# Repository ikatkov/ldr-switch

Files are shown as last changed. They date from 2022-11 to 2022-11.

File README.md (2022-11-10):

# Tiny LDR switch

Based on $0.60 Attiny13 MCU. 1kB flash, 256B ram.

It turns ON when it's dark (user configurable), stays ON for X hours, turns OFF, and waits till it's dark again. Intended to use with a battery, so it only consumes 5uA. Watch out for input power voltage. Min is 1.8V max is 5.5V. Max load current ~2A. Exceeds this and PCB traces will heat up and unsolder components.
There is simple diode craw-bar reverse voltage protection for MCU.

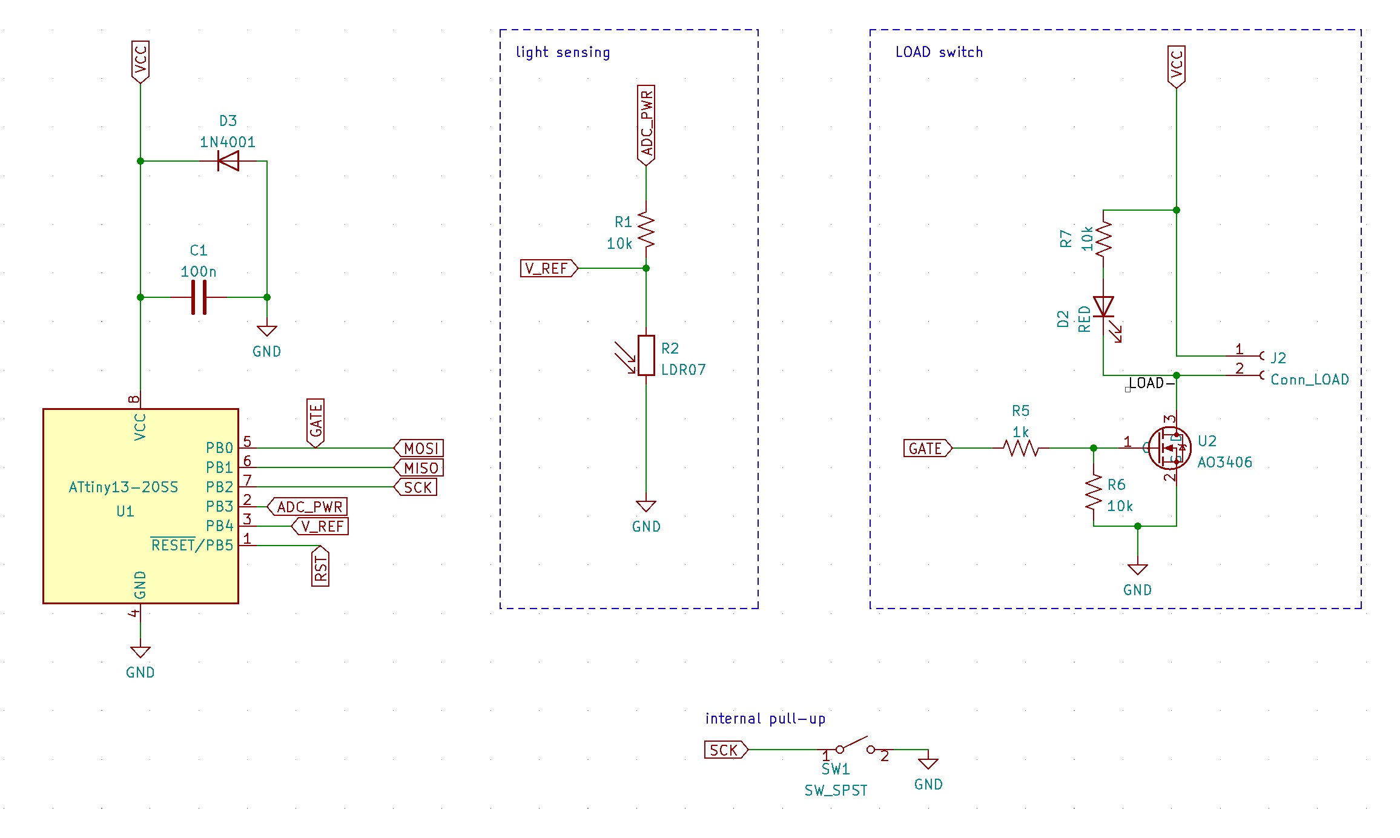
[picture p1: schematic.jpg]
Schematic


# Manufacturing

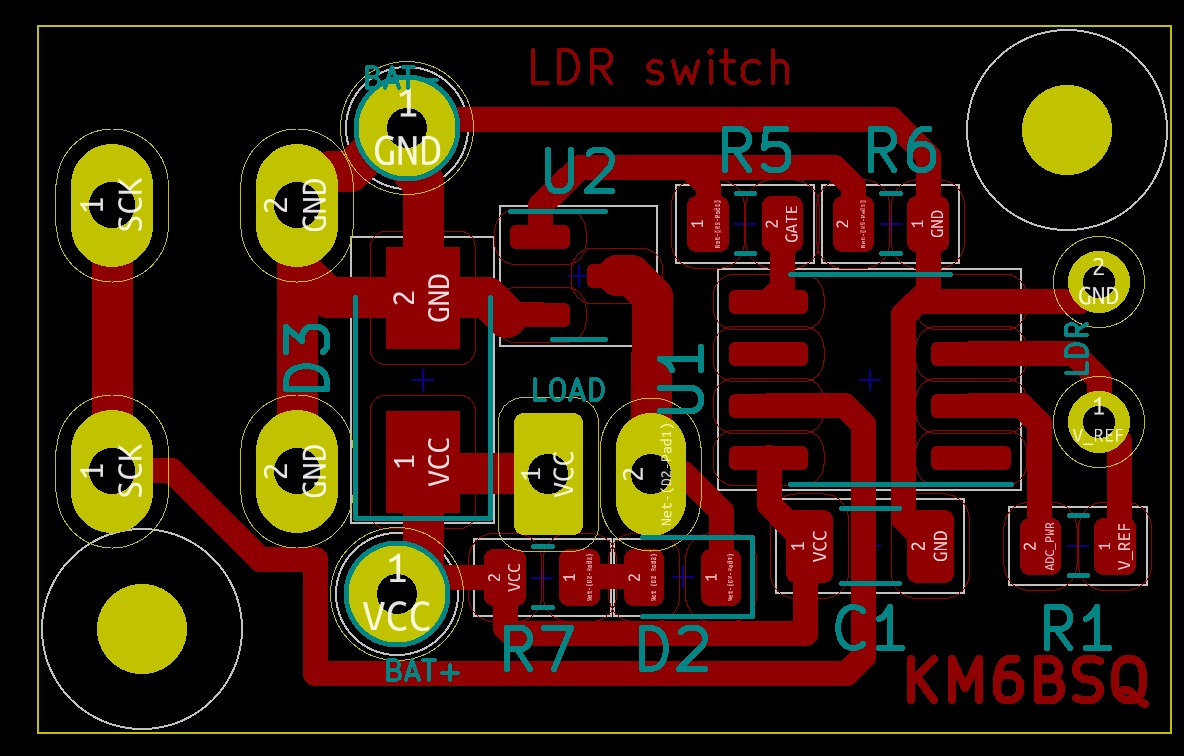
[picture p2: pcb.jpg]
PCB

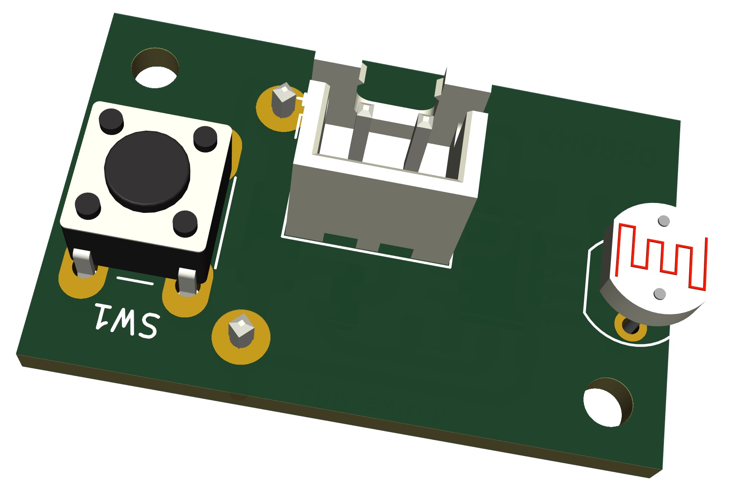
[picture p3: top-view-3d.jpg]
Top view

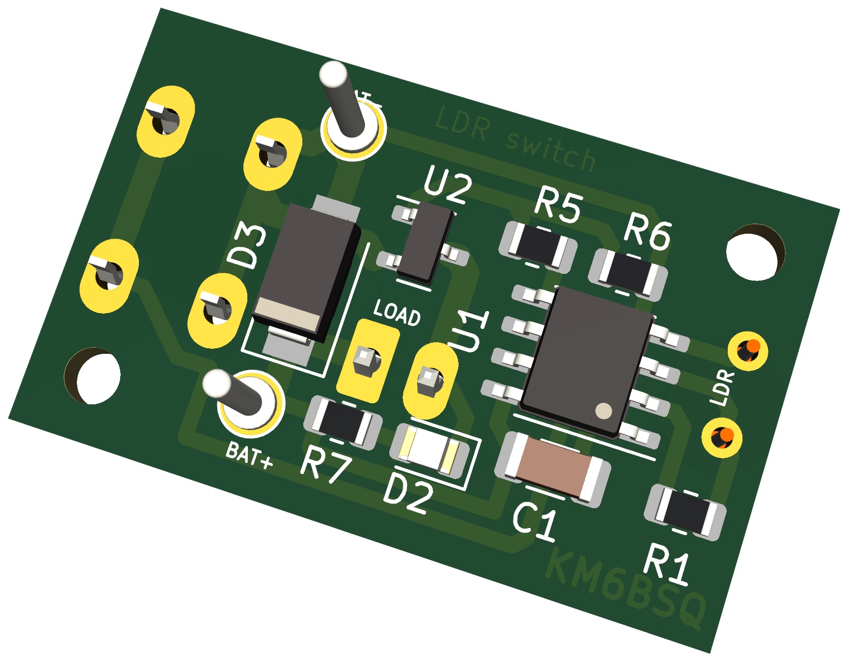
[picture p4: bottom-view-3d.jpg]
Bottom view

[PCB](./kicad/main.step)

[Enclosure lid](lid.stl)

[Enclosure base](base.stl)

# Code

MCU sleeps all the time. Wakes up via watchdog interrupt every 4 sec to measure light. It powers the LDR/R voltage divider via the MCU pin, takes ADC measurements, and turns off the pin to save power. Compares measured light with the thresholds and goes into ON, OFF, or WAIT_FOR_RESET state. Depending on the state, it turns the load ON/OFF.
A short button press wakes it from sleep, forcing it to measure light. 

* If it was in the OFF state - record the new "dark" light threshold, turn the load ON, start the auto-turn-off timer, and go into the ON state.
* If it was in the ON state - it turns the load OFF and goes into the WAIT_FOR_RESET state.

A long button press lets you set the auto-turn-off timer duration. Keep the button pressed and watch the LOAD blink. 1 blink == 1 hour, 2 blinks == 2 hours etc. Release the button once the desired number of hours is indicated. 

When the timer is UP, the load turns OFF, and the MCU transitions into the WAIT_FOR_RESET state.

There are two light thresholds in the code. 

* "dark" - once it's darker than this, MCU turns the load ON and goes into the ON state
* "bright" - once it's brighter than this, MCU goes from  WAIT_FOR_RESET into the OFF state. 

WAIT_FOR_RESET is meant to capture the daytime reset so that the switch is only active once per day for X hours.

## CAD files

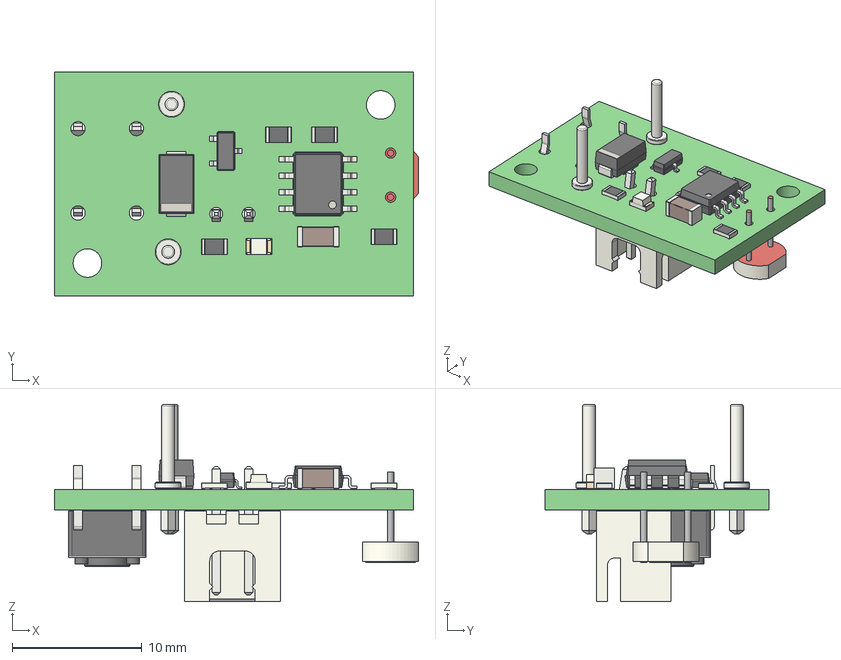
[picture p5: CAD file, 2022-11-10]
kicad/main.step
28.1 x 17.3 x 15.2 mm
main PCB

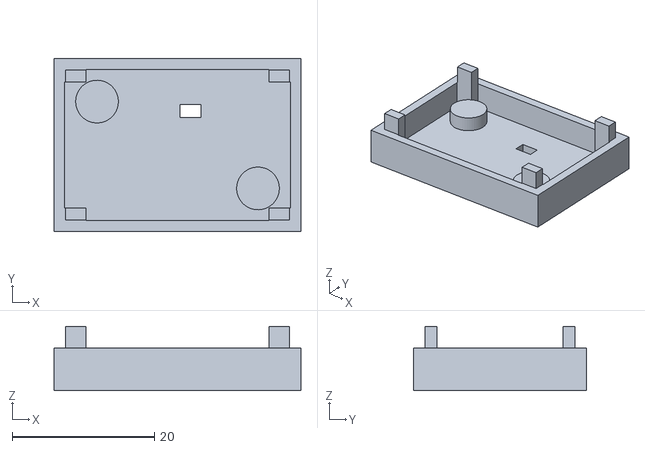
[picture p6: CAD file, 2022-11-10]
base.stl
34.7 x 24.3 x 9.00

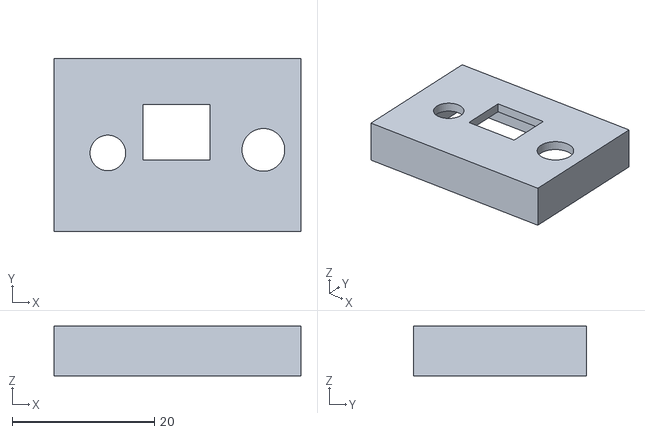
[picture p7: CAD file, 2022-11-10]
lid.stl
34.7 x 24.3 x 7.00

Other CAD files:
enclosure.f3z

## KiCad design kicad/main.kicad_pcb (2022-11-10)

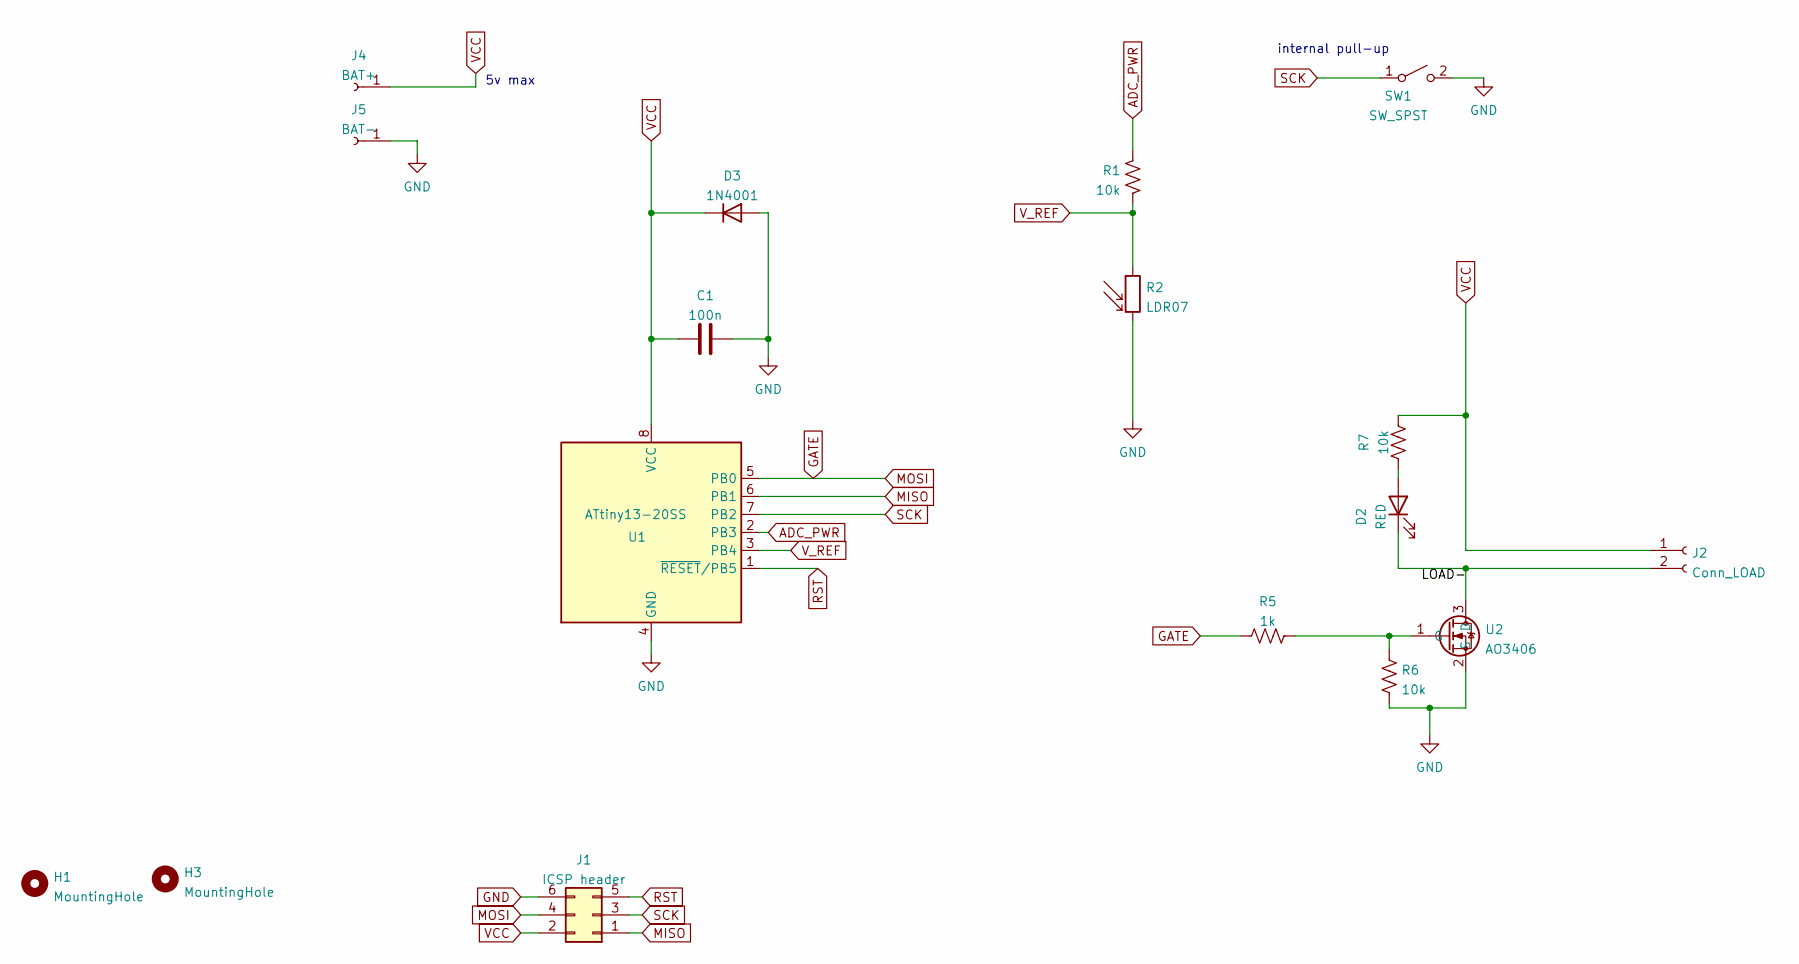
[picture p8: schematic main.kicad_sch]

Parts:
C1: 100n; C_1206_3216Metric
D2: RED; LED_0805_2012Metric
D3: 1N4001; D_SMA
H1, H3: MountingHole; MountingHole_2.2mm_M2
J1: ICSP header; PinHeader_2x03_P2.54mm_Vertical
J2: Conn_LOAD; JST_XH_B2B-XH-A_1x02_P2.50mm_Vertical
J4: BAT+; Pin_D1.0mm_L10.0mm
J5: BAT-; Pin_D1.0mm_L10.0mm
R1, R6, R7: 10k; R_0805_2012Metric
R2: LDR07; R_LDR_5.1x4.3mm_P3.4mm_Vertical
R5: 1k; R_0805_2012Metric
SW1: SW_SPST; SW_PUSH_6mm
U1: ATtiny13-20SS; SOIC-8_3.9x4.9mm_P1.27mm
U2: AO3406; SOT-23

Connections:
ADC_PWR: R1.2, U1.2 (PB3)
GATE: J1.4, R5.2, U1.5 (PB0)
GND: C1.2, D3.2 (A), J5.1, R2.2, R6.1, SW1.2 (B), U1.4 (GND), U2.2 (S)
MISO: J1.1, U1.6 (PB1)
unnamed: D2.1 (K), J2.2, U2.3 (D)
unnamed: D2.2 (A), R7.1
unnamed: R5.1, R6.2, U2.1 (G)
RST: J1.5, U1.1 (~RESET/PB5)
SCK: J1.3, SW1.1 (A), U1.7 (PB2)
VCC: C1.1, D3.1 (K), J1.2, J2.1, J4.1, R7.2, U1.8 (VCC)
V_REF: R1.1, R2.1, U1.3 (PB4)

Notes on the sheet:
internal pull-up
5v max

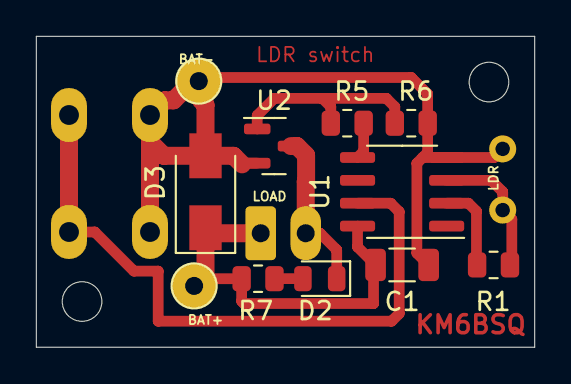
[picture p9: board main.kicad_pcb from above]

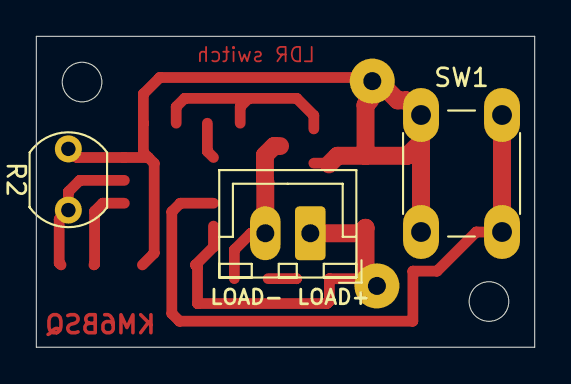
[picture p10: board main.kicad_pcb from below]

Board: 4 copper layers, 27.7 x 17.3 mm, 16 parts (3 on the bottom side), 9 nets.

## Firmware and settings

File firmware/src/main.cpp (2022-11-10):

#include "Arduino.h"
#include <EEPROM.h>
#include <avr/sleep.h>
#include <avr/wdt.h>

static uint8_t lighOnDurationHours = 2;

#define LOAD_PIN PB0      // pin5 Attiny13
#define ADC_POWER_PIN PB3 //  pin2 on Attiny13
#define ADC_PIN A2        // PB4, pin3 Attiny13
#define INT_PIN PB2       // also button pin, pin7 Attiny13

static uint16_t lightThresholdDark = 700;
#define lightThresholdBright 350
#define LIGHT_THRESHOLD_HYSTERESIS 10

static enum state_t {
    OFF,
    ON,
    WAIT_FOR_RESET
} STATE;

static int32_t timer_sec = 0;

template <class T>
int EEPROM_writeAnything(int address, const T &value)
{
    const byte *p = (const byte *)(const void *)&value;
    uint8_t i;
    for (i = 0; i < sizeof(value); i++)
        EEPROM.write(address++, *p++);
    return i;
}

template <class T>
int EEPROM_readAnything(int address, T &value)
{
    byte *p = (byte *)(void *)&value;
    uint16_t i;
    for (i = 0; i < sizeof(value); i++)
        *p++ = EEPROM.read(address++);
    return i;
}

void powerDown(uint8_t sleepTime);
void blink(uint8_t times, uint16_t delayTime = 200);
void configureButtonInterrupt(bool enable);

EMPTY_INTERRUPT(PCINT0_vect);
EMPTY_INTERRUPT(WDT_vect)

void setlighOnDurationHours()
{
    uint8_t counter = 0;
    while (digitalRead(INT_PIN) == LOW)
    {
        counter++;
        if (counter > 8)
            counter = 1;
        blink(counter);
        delay(2000);
    }
    if (counter > 0 && counter != lighOnDurationHours)
    {
        lighOnDurationHours = counter;
        EEPROM_writeAnything(2, lighOnDurationHours);
    }
}

void readButton(uint16_t lightLevel)
{
    if (digitalRead(INT_PIN) == LOW)
    {
        if (STATE == ON)
        {
            digitalWrite(LOAD_PIN, LOW);
            STATE = WAIT_FOR_RESET;
            delay(2000); // debounce
        }
        else if (STATE == OFF || STATE == WAIT_FOR_RESET)
        {
            STATE = ON;
            blink(lighOnDurationHours);
            delay(1000); // blink delay + debounce
            digitalWrite(LOAD_PIN, HIGH);
            timer_sec = lighOnDurationHours * 60 * 60;

            // set new lightThresholdDark
            lightThresholdDark = lightLevel;

            EEPROM_writeAnything(0, lightThresholdDark);
        }
        setlighOnDurationHours();
    }
}

void powerDown(uint8_t sleepTime)
{
    ADCSRA &= ~(1 << ADEN); // adc OFF
    wdt_enable(sleepTime);  // watchdog
    WDTCR |= _BV(WDTIE);

    do
    {
        set_sleep_mode(SLEEP_MODE_PWR_DOWN);
        cli(); // Disable interrupts
        sleep_enable();
        sleep_bod_disable();
        sei(); // Enable interrupts
        sleep_cpu();

        sleep_disable();
        sei();
    } while (0);

    ADCSRA |= (1 << ADEN); // adc ON
}

void blink(uint8_t times, uint16_t delayTime)
{
    for (int i = times; i > 0; i--)
    {
        digitalWrite(LOAD_PIN, HIGH);
        delay(delayTime);
        digitalWrite(LOAD_PIN, LOW);
        delay(delayTime);
        wdt_reset();
    }
}

void setup()
{
    pinMode(ADC_POWER_PIN, OUTPUT);
    pinMode(ADC_PIN, INPUT);        // ADC
    pinMode(INT_PIN, INPUT_PULLUP); // button
    pinMode(LOAD_PIN, OUTPUT);      // gate

    analogReference(DEFAULT);

    cli();
    GIMSK |= _BV(PCIE);   //  Enable PCINT interrupt in the general interrupt mask
    PCMSK |= _BV(PCINT2); // Enable interrupt handler (ISR) for our chosen interrupt pin (PCINT2/PB2/pin 7)
    sei();

    EEPROM_readAnything(0, lightThresholdDark);
    if (lightThresholdDark < 0 || lightThresholdDark > 1024)
    {
        lightThresholdDark = 700;
        EEPROM_writeAnything(0, lightThresholdDark);
    }
    EEPROM_readAnything(2, lighOnDurationHours);
    if (lighOnDurationHours < 1 || lighOnDurationHours > 8)
    {
        lighOnDurationHours = 2;
    }

    blink(lighOnDurationHours);
}

void loop()
{
    digitalWrite(ADC_POWER_PIN, HIGH);
    uint16_t lightLevel = analogRead(ADC_PIN);
    digitalWrite(ADC_POWER_PIN, LOW);
    readButton(lightLevel);

    if (STATE == WAIT_FOR_RESET && lightLevel <= lightThresholdBright)
    {
        STATE = OFF;
    }

    if (STATE == OFF && lightLevel >= lightThresholdDark)
    {
        digitalWrite(LOAD_PIN, HIGH);
        timer_sec = lighOnDurationHours * 60 * 60;
        STATE = ON;
    }
    else if (STATE == ON && timer_sec <= 0)
    {
        digitalWrite(LOAD_PIN, LOW);
        STATE = WAIT_FOR_RESET;
    }
    else if (STATE == ON && lightLevel < lightThresholdDark - LIGHT_THRESHOLD_HYSTERESIS)
    {
        digitalWrite(LOAD_PIN, LOW);
        STATE = OFF;
    }

    powerDown(WDTO_4S);
    if (timer_sec > 0)
    {
        timer_sec -= 4;
    }
}

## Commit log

2022-11-09 code is broken, pcb OK
    [main.kicad_pcb, main.kicad_sch, main.sch]
2022-11-10 light duration settings
    [main.kicad_sch]
2022-11-10 clean up
    [main.kicad_pcb, main.kicad_sch, main.step]
2022-11-10 add README description and images
    [main.kicad_sch]
2022-11-10 add enclosure files
    [base.stl, enclosure.f3z, lid.stl]
